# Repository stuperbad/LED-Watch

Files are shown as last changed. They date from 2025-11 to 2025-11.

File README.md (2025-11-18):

# LED-Watch
first schematic progress commit. adding RGB sketch schematic as well as
completed single LED ring sketch. need to add buttons and sort out AND
gates in the RGB sketch.
Product Ideas.. data sheets and store locations:

Boards options 

27 i/o pins and in the current sketch: https://www.digikey.com/en/products/detail/microchip-technology/ATMEGA4808-MUR/10444956

32 i/o pins: https://www.digikey.com/en/products/detail/microchip-technology/ATMEGA1284P-MU/1914520

LEDs options

addressable 1mm RGB: 
https://www.sparkfun.com/smd-led-addressable-rgb-apa-104-1010-pack-of-20.html
datasheet: https://cdn.sparkfun.com/assets/3/c/c/0/9/SparkFun_APA-104-1010__5mA__LED_Datasheet.pdf

nonaddressable 1mm RGB: 
https://www.digikey.com/en/products/detail/harvatek-corporation/B36J3RGB-F6C0001H4U1930/13588748

discrete white 0603:
https://www.digikey.com/en/products/detail/everlight-electronics-co-ltd/CSP0603AN101-WP30300563001-3T/15286660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

Button Options

19 cent 3.4mm square: https://www.digikey.com/en/products/detail/same-sky-formerly-cui-devices/TS21-34-035-BK-260-SMT-TR/21186457

8 cent 5.2mm square: https://www.digikey.com/en/products/detail/c-k/G01008829/16500348

Battery Parts:

Lipo Connector 
Thru-hole - 2mm.. they make 1mm mb? 
https://www.digikey.com/en/products/detail/jst-sales-america-inc/B2B-PH-K-S/926611

Coin Cell Harness
20mm dia. 3.
Do i need a negative connector? is SMD okay?
https://www.digikey.com/en/products/detail/keystone-electronics/3034TR/4499408

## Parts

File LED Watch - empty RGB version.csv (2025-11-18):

Reference | Qty | Value | DNP | Exclude from BOM | Exclude from Board | Footprint | Datasheet
RGB_LED1,RGB_LED2,RGB_LED3,RGB_LED4,RGB_LED5,RGB_LED6,RGB_LED7,RGB_LED8,RGB_LED9,RGB_LED10,RGB_LED11,RGB_LED12,RGB_LED13,RGB_LED14,RGB_LED15,RGB_LED16,RGB_LED17,RGB_LED18,RGB_LED19,RGB_LED20,RGB_LED21,RGB_LED22,RGB_LED23,RGB_LED24,RGB_LED25,RGB_LED26,RGB_LED27,RGB_LED28,RGB_LED29,RGB_LED30,RGB_LED31,RGB_LED32,RGB_LED33,RGB_LED34,RGB_LED35,RGB_LED36,RGB_LED37,RGB_LED38,RGB_LED39,RGB_LED40,RGB_LED41,RGB_LED42,RGB_LED43,RGB_LED44,RGB_LED45,RGB_LED46,RGB_LED47,RGB_LED48,RGB_LED49,RGB_LED50,RGB_LED51,RGB_LED52,RGB_LED53,RGB_LED54,RGB_LED55,RGB_LED56,RGB_LED57,RGB_LED58,RGB_LED59,RGB_LED60,RGB_LED61,RGB_LED62,RGB_LED63,RGB_LED64,RGB_LED65,RGB_LED66,RGB_LED67,RGB_LED68,RGB_LED69,RGB_LED70,RGB_LED71,RGB_LED72,RGB_LED73,RGB_LED74,RGB_LED75,RGB_LED76,RGB_LED77,RGB_LED78,RGB_LED79,RGB_LED80,RGB_LED81,RGB_LED82,RGB_LED83,RGB_LED84,RGB_LED85,RGB_LED86,RGB_LED87,RGB_LED88,RGB_LED89,RGB_LED90,RGB_LED91,RGB_LED92,RGB_LED93,RGB_LED94,RGB_LED95,RGB_LED96,RGB_LED97,RGB_LED98,RGB_LED99,RGB_LED100,RGB_LED101,RGB_LED102,RGB_LED103,RGB_LED104,RGB_LED105,RGB_LED106,RGB_LED107,RGB_LED108,RGB_LED109,RGB_LED110,RGB_LED111,RGB_LED112,RGB_LED113,RGB_LED114,RGB_LED115,RGB_LED116,RGB_LED117,RGB_LED118,RGB_LED119,RGB_LED120,RGB_LED121,RGB_LED122,RGB_LED123,RGB_LED124,RGB_LED125,RGB_LED126,RGB_LED132,RGB_LED133,RGB_LED134,RGB_LED135,RGB_LED136,RGB_LED137 | 132 | LTST-C19HE1WT |  |  |  | digikey-footprints:LED_Dual0603 | http://optoelectronics.liteon.com/upload/download/DS22-2008-0044/LTST-C19HE1WT.pdf
U1 | 1 | ATmega165PA-A |  |  |  | Package_QFP:TQFP-64_14x14mm_P0.8mm | http://ww1.microchip.com/downloads/en/DeviceDoc/atmel-8285-8-bit-avr-microcontroller-atmega165a_pa_325a_pa_3250a_pa_645a_p_6450a_p_datasheet.pdf

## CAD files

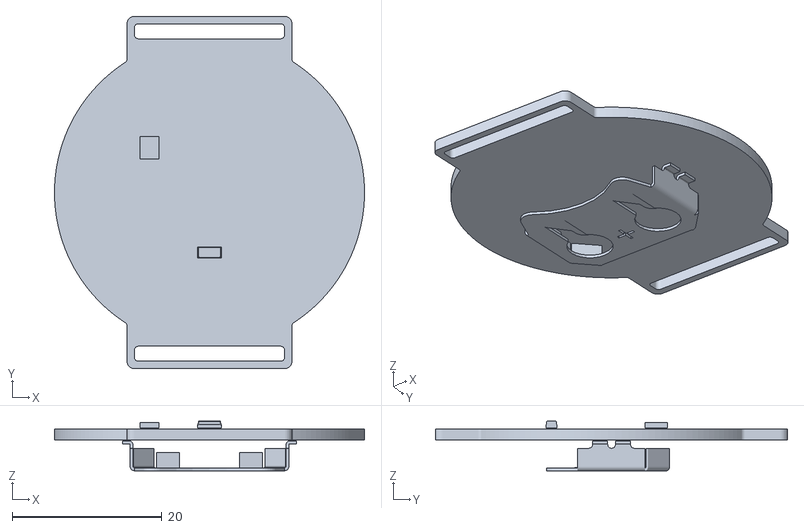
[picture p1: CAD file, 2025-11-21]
LED Watch.stl
41.3 x 47.0 x 6.61

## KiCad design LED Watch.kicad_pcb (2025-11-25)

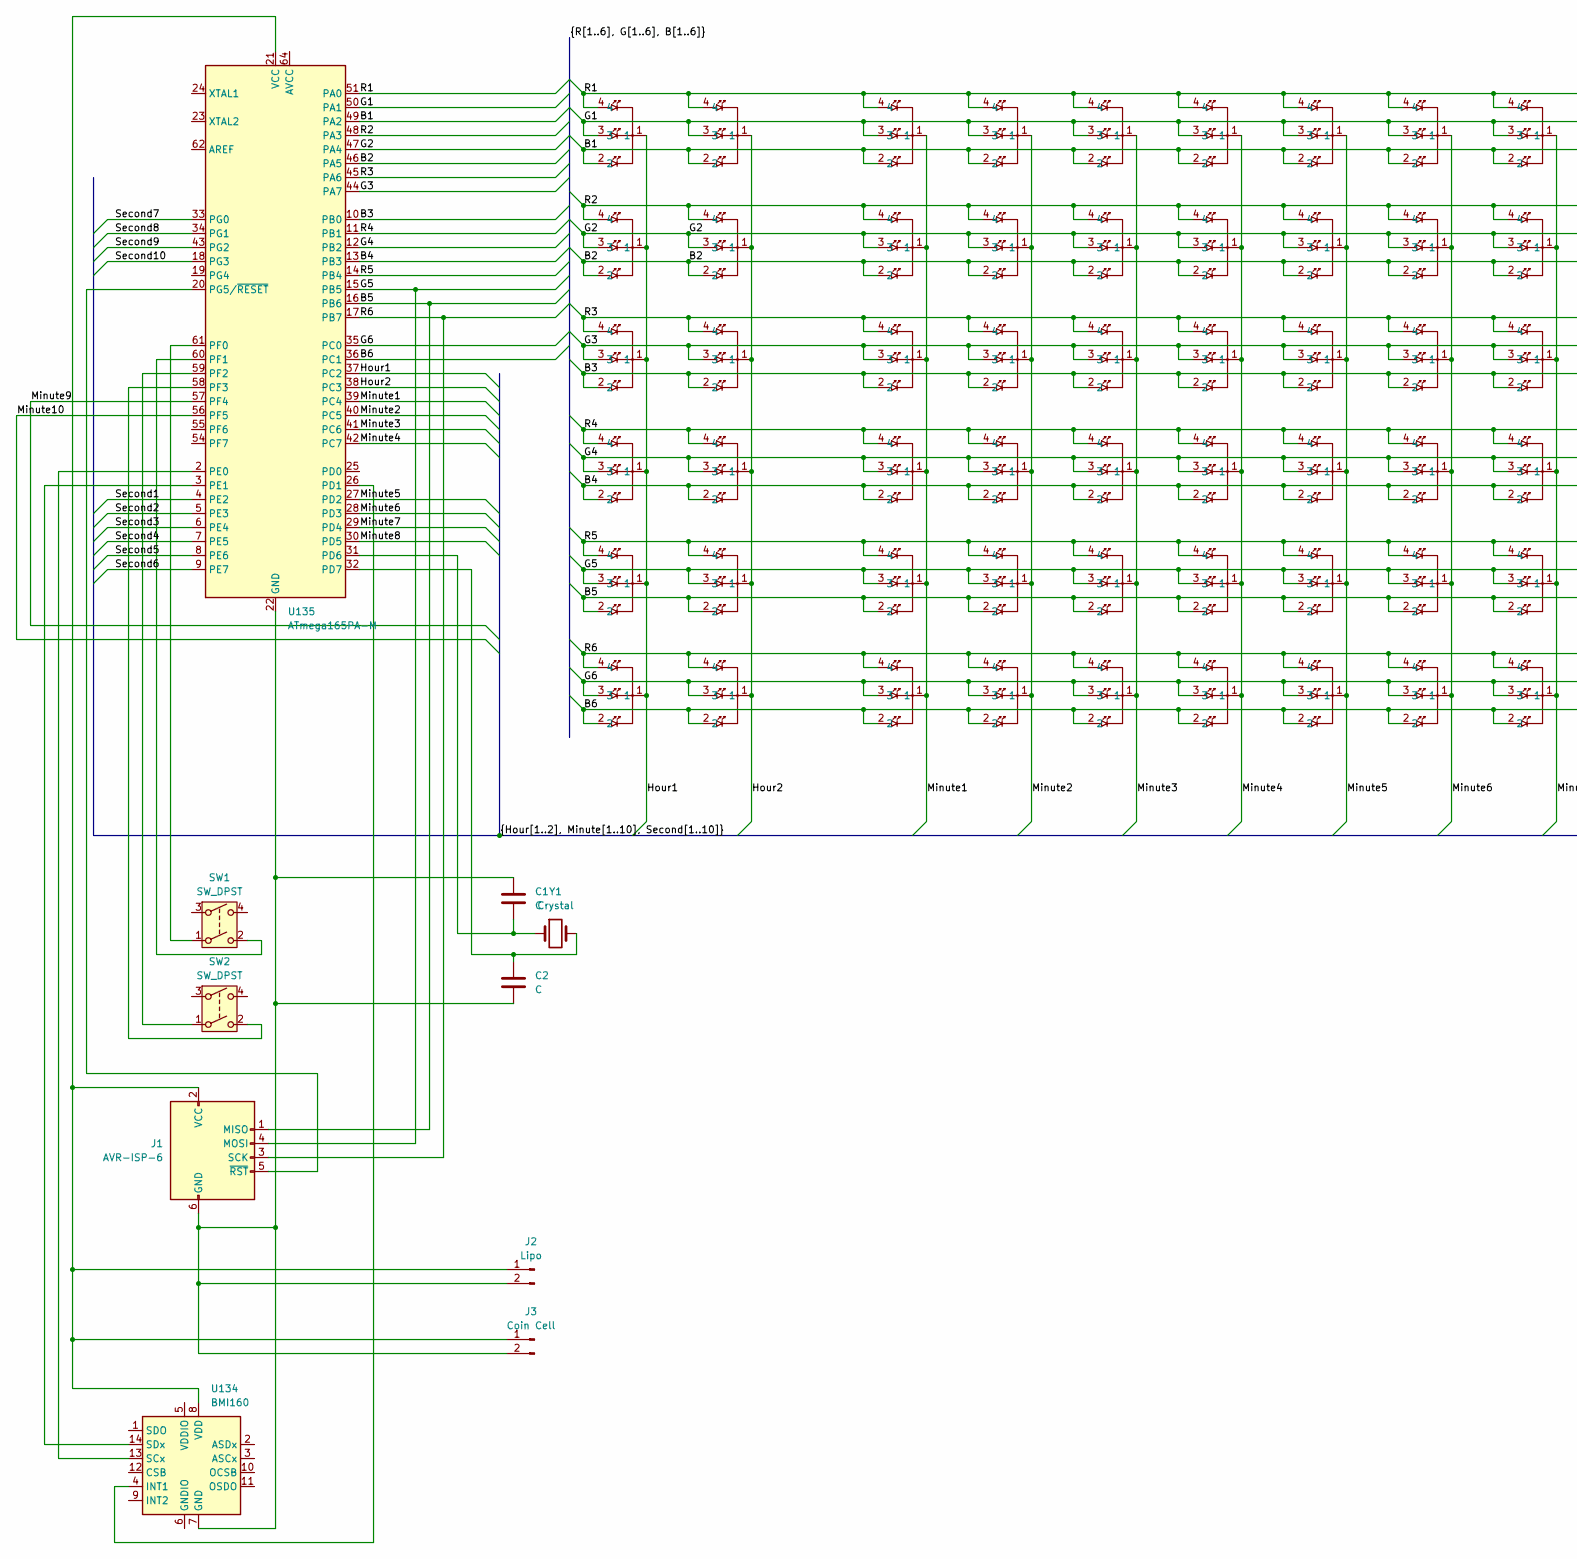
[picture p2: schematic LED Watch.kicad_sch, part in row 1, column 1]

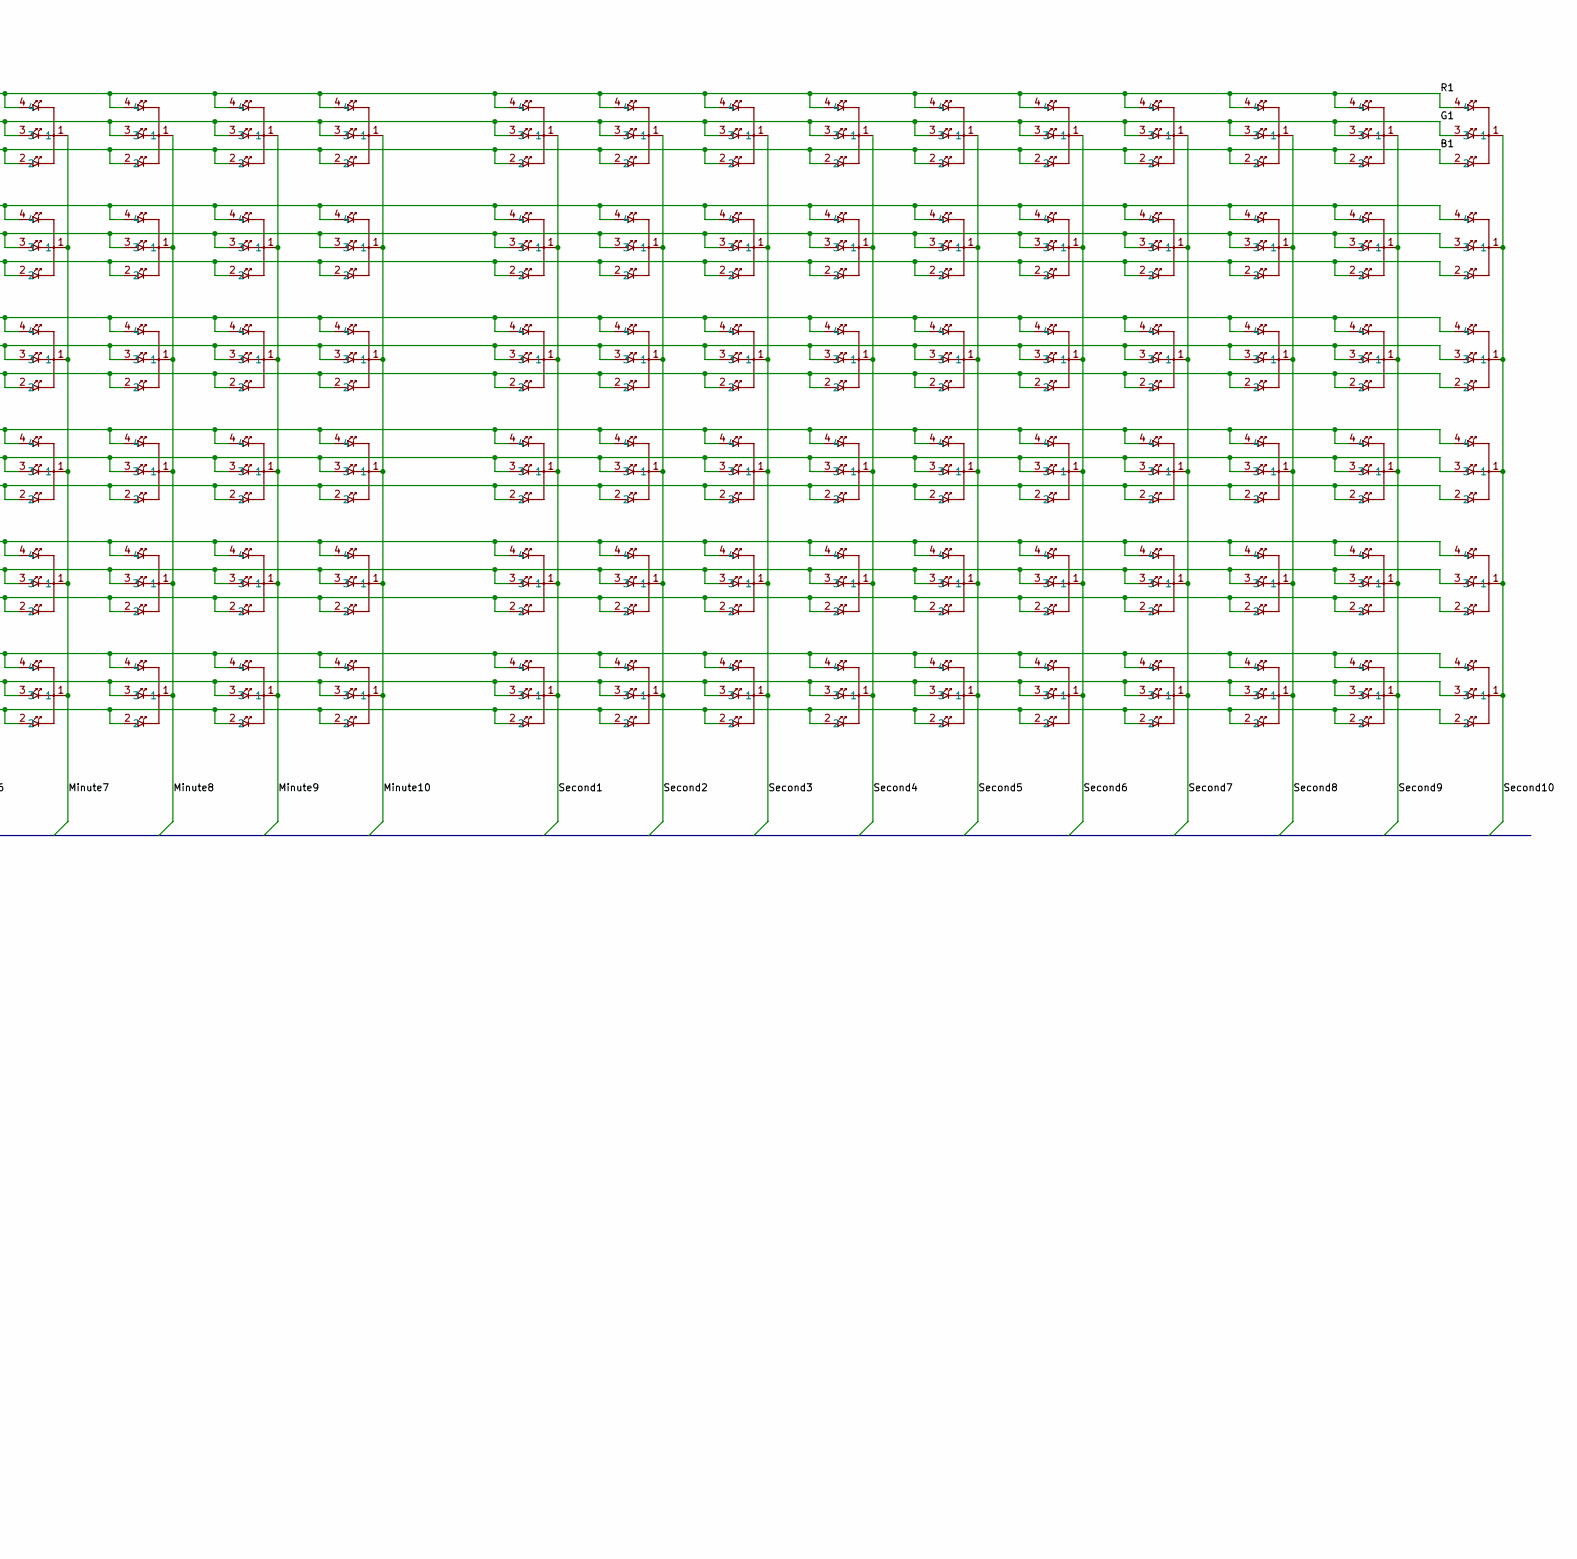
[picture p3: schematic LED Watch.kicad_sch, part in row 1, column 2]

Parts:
C1, C2: C; C_0201_0603Metric
J1: AVR-ISP-6; Tag-Connect_TC2030-IDC-NL_2x03_P1.27mm_Vertical
J2: Lipo; JST_SH_SM02B-SRSS-TB_1x02-1MP_P1.00mm_Horizontal
J3: Coin Cell; BatteryHolder_Keystone_3034_1x20mm
SW1, SW2: SW_DPST; SW_TS21-34-035-BK-260-SMT-TR
U2, U3, U4, U5, U6, U7, U8, U9, U10, U11, U12, U13, U14, U15, U16, U17, U18, U19, U20, U21, U22, U23, U24, U25, U26, U27, U28, U29, U30, U31, U32, U33, U34, U35, U36, U37, U38, U39, U40, U41, U42, U43, U44, U45, U46, U47, U48, U49, U50, U51, U52, U53, U54, U55, U56, U57, U58, U59, U60, U61, U62, U63, U64, U65, U66, U67, U68, U69, U70, U71, U72, U73, U74, U75, U76, U77, U78, U79, U80, U81, U82, U83, U84, U85, U86, U87, U88, U89, U90, U91, U92, U93, U94, U95, U96, U97, U98, U99, U100, U101, U102, U103, U104, U105, U106, U107, U108, U109, U110, U111, U112, U113, U114, U115, U116, U117, U118, U119, U120, U121, U122, U123, U124, U125, U126, U127, U128, U129, U130, U131, U132, U133: B39D3RGB-F6C0001HOU1930; B39D3RGB-F6C0001HOU1930_HVK; MPN LTST-C19HE1WT; Digi-Key_PN 160-2162-1-ND
U134: BMI160; Bosch_LGA-14_3x2.5mm_P0.5mm
U135: ATmega165PA-M; QFN-64-1EP_9x9mm_P0.5mm_EP5.4x5.4mm
Y1: Crystal; Crystal_SMD_3215-2Pin_3.2x1.5mm

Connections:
/B1: U2.2, U8.2, U14.2, U20.2, U26.2, U32.2, U38.2, U44.2, U50.2, U56.2, U62.2, U68.2, U74.2, U80.2, U86.2, U92.2, U98.2, U104.2, U110.2, U116.2, U122.2, U128.2, U135.49 (PA2)
/B2: U3.2, U9.2, U15.2, U21.2, U27.2, U33.2, U39.2, U45.2, U51.2, U57.2, U63.2, U69.2, U75.2, U81.2, U87.2, U93.2, U99.2, U105.2, U111.2, U117.2, U123.2, U129.2, U135.46 (PA5)
/B3: U4.2, U10.2, U16.2, U22.2, U28.2, U34.2, U40.2, U46.2, U52.2, U58.2, U64.2, U70.2, U76.2, U82.2, U88.2, U94.2, U100.2, U106.2, U112.2, U118.2, U124.2, U130.2, U135.10 (PB0)
/B4: U5.2, U11.2, U17.2, U23.2, U29.2, U35.2, U41.2, U47.2, U53.2, U59.2, U65.2, U71.2, U77.2, U83.2, U89.2, U95.2, U101.2, U107.2, U113.2, U119.2, U125.2, U131.2, U135.13 (PB3)
/B5: J1.1 (MISO), U6.2, U12.2, U18.2, U24.2, U30.2, U36.2, U42.2, U48.2, U54.2, U60.2, U66.2, U72.2, U78.2, U84.2, U90.2, U96.2, U102.2, U108.2, U114.2, U120.2, U126.2, U132.2, U135.16 (PB6)
/B6: U7.2, U13.2, U19.2, U25.2, U31.2, U37.2, U43.2, U49.2, U55.2, U61.2, U67.2, U73.2, U79.2, U85.2, U91.2, U97.2, U103.2, U109.2, U115.2, U121.2, U127.2, U133.2, U135.36 (PC1)
/G1: U2.3, U8.3, U14.3, U20.3, U26.3, U32.3, U38.3, U44.3, U50.3, U56.3, U62.3, U68.3, U74.3, U80.3, U86.3, U92.3, U98.3, U104.3, U110.3, U116.3, U122.3, U128.3, U135.50 (PA1)
/G2: U3.3, U9.3, U15.3, U21.3, U27.3, U33.3, U39.3, U45.3, U51.3, U57.3, U63.3, U69.3, U75.3, U81.3, U87.3, U93.3, U99.3, U105.3, U111.3, U117.3, U123.3, U129.3, U135.47 (PA4)
/G3: U4.3, U10.3, U16.3, U22.3, U28.3, U34.3, U40.3, U46.3, U52.3, U58.3, U64.3, U70.3, U76.3, U82.3, U88.3, U94.3, U100.3, U106.3, U112.3, U118.3, U124.3, U130.3, U135.44 (PA7)
/G4: U5.3, U11.3, U17.3, U23.3, U29.3, U35.3, U41.3, U47.3, U53.3, U59.3, U65.3, U71.3, U77.3, U83.3, U89.3, U95.3, U101.3, U107.3, U113.3, U119.3, U125.3, U131.3, U135.12 (PB2)
/G5: J1.4 (MOSI), U6.3, U12.3, U18.3, U24.3, U30.3, U36.3, U42.3, U48.3, U54.3, U60.3, U66.3, U72.3, U78.3, U84.3, U90.3, U96.3, U102.3, U108.3, U114.3, U120.3, U126.3, U132.3, U135.15 (PB5)
/G6: U7.3, U13.3, U19.3, U25.3, U31.3, U37.3, U43.3, U49.3, U55.3, U61.3, U67.3, U73.3, U79.3, U85.3, U91.3, U97.3, U103.3, U109.3, U115.3, U121.3, U127.3, U133.3, U135.35 (PC0)
/Hour1: U2.1, U3.1, U4.1, U5.1, U6.1, U7.1, U135.37 (PC2)
/Hour2: U8.1, U9.1, U10.1, U11.1, U12.1, U13.1, U135.38 (PC3)
/Minute1: U14.1, U15.1, U16.1, U17.1, U18.1, U19.1, U135.39 (PC4)
/Minute2: U20.1, U21.1, U22.1, U23.1, U24.1, U25.1, U135.40 (PC5)
/Minute3: U26.1, U27.1, U28.1, U29.1, U30.1, U31.1, U135.41 (PC6)
/Minute4: U32.1, U33.1, U34.1, U35.1, U36.1, U37.1, U135.42 (PC7)
/Minute5: U38.1, U39.1, U40.1, U41.1, U42.1, U43.1, U135.27 (PD2)
/Minute6: U44.1, U45.1, U46.1, U47.1, U48.1, U49.1, U135.28 (PD3)
/Minute7: U50.1, U51.1, U52.1, U53.1, U54.1, U55.1, U135.29 (PD4)
/Minute8: U56.1, U57.1, U58.1, U59.1, U60.1, U61.1, U135.30 (PD5)
/Minute9: U62.1, U63.1, U64.1, U65.1, U66.1, U67.1, U135.57 (PF4)
/Minute10: U68.1, U69.1, U70.1, U71.1, U72.1, U73.1, U135.56 (PF5)
/R1: U2.4, U8.4, U14.4, U20.4, U26.4, U32.4, U38.4, U44.4, U50.4, U56.4, U62.4, U68.4, U74.4, U80.4, U86.4, U92.4, U98.4, U104.4, U110.4, U116.4, U122.4, U128.4, U135.51 (PA0)
/R2: U3.4, U9.4, U15.4, U21.4, U27.4, U33.4, U39.4, U45.4, U51.4, U57.4, U63.4, U69.4, U75.4, U81.4, U87.4, U93.4, U99.4, U105.4, U111.4, U117.4, U123.4, U129.4, U135.48 (PA3)
/R3: U4.4, U10.4, U16.4, U22.4, U28.4, U34.4, U40.4, U46.4, U52.4, U58.4, U64.4, U70.4, U76.4, U82.4, U88.4, U94.4, U100.4, U106.4, U112.4, U118.4, U124.4, U130.4, U135.45 (PA6)
/R4: U5.4, U11.4, U17.4, U23.4, U29.4, U35.4, U41.4, U47.4, U53.4, U59.4, U65.4, U71.4, U77.4, U83.4, U89.4, U95.4, U101.4, U107.4, U113.4, U119.4, U125.4, U131.4, U135.11 (PB1)
/R5: U6.4, U12.4, U18.4, U24.4, U30.4, U36.4, U42.4, U48.4, U54.4, U60.4, U66.4, U72.4, U78.4, U84.4, U90.4, U96.4, U102.4, U108.4, U114.4, U120.4, U126.4, U132.4, U135.14 (PB4)
/R6: J1.3 (SCK), U7.4, U13.4, U19.4, U25.4, U31.4, U37.4, U43.4, U49.4, U55.4, U61.4, U67.4, U73.4, U79.4, U85.4, U91.4, U97.4, U103.4, U109.4, U115.4, U121.4, U127.4, U133.4, U135.17 (PB7)
/Second1: U74.1, U75.1, U76.1, U77.1, U78.1, U79.1, U135.4 (PE2)
/Second2: U80.1, U81.1, U82.1, U83.1, U84.1, U85.1, U135.5 (PE3)
/Second3: U86.1, U87.1, U88.1, U89.1, U90.1, U91.1, U135.6 (PE4)
/Second4: U92.1, U93.1, U94.1, U95.1, U96.1, U97.1, U135.7 (PE5)
/Second5: U98.1, U99.1, U100.1, U101.1, U102.1, U103.1, U135.8 (PE6)
/Second6: U104.1, U105.1, U106.1, U107.1, U108.1, U109.1, U135.9 (PE7)
/Second7: U110.1, U111.1, U112.1, U113.1, U114.1, U115.1, U135.33 (PG0)
/Second8: U116.1, U117.1, U118.1, U119.1, U120.1, U121.1, U135.34 (PG1)
/Second9: U122.1, U123.1, U124.1, U125.1, U126.1, U127.1, U135.43 (PG2)
/Second10: U128.1, U129.1, U130.1, U131.1, U132.1, U133.1, U135.18 (PG3)
unnamed: C1.1, C2.2, J1.6 (GND), J2.2, J3.2, U134.7 (GND), U135.22 (GND), U135.53 (GND), U135.63 (GND), U135.65 (GND)
unnamed: J1.2 (VCC), J2.1, J3.1, U134.8 (VDD), U135.21 (VCC), U135.52 (VCC)
unnamed: J1.5 (~RST), U135.20 (PG5/~RESET)
unnamed: U134.4 (INT1), U135.26 (PD1)
unnamed: U134.13 (SCx), U135.2 (PE0)
unnamed: U134.14 (SDx), U135.3 (PE1)
unnamed: C1.2, U135.31 (PD6), Y1.1
unnamed: C2.1, U135.32 (PD7), Y1.2
unnamed: SW1.1, U135.61 (PF0)
unnamed: SW1.2, U135.60 (PF1)
unnamed: SW2.1, U135.59 (PF2)
unnamed: SW2.2, U135.58 (PF3)

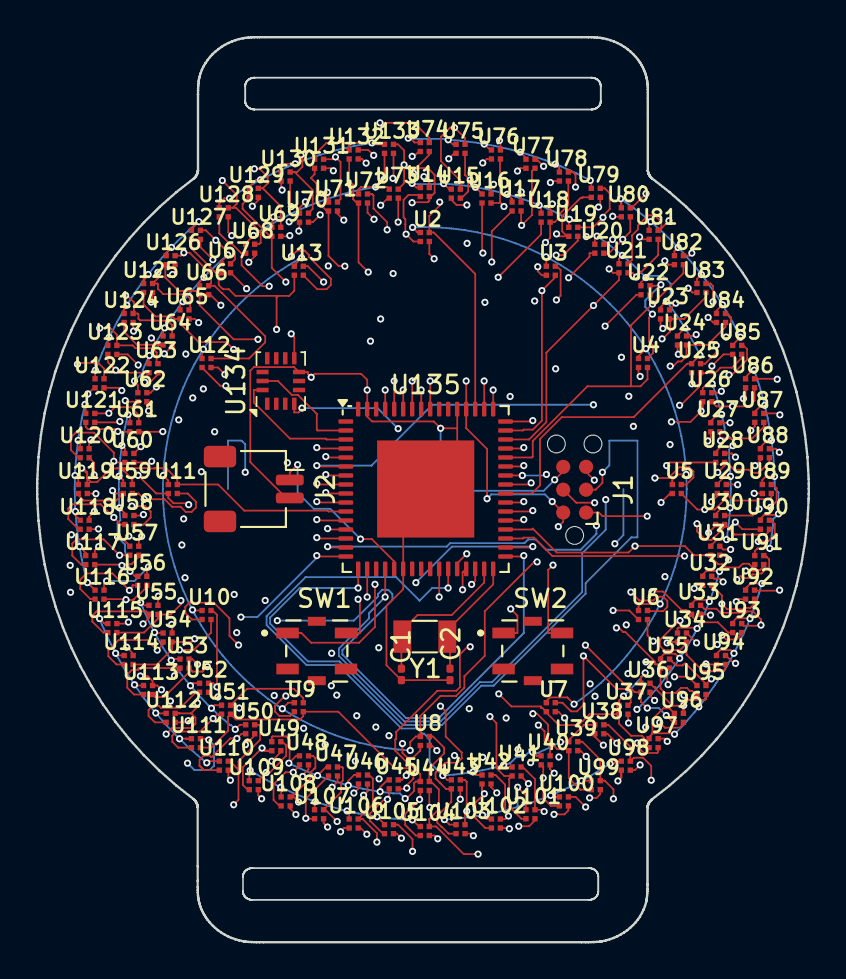
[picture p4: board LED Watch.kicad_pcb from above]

Board: 4 copper layers, 42.9 x 50.3 mm, 142 parts (1 on the bottom side), 52 nets.

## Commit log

2025-09-09 adding kicad files
    [LED Watch.kicad_pcb, LED Watch.kicad_sch]
2025-09-16 first schematic progress commit. adding RGB sketch schematic as well as completed single LED ring sketch. need to add buttons and sort out AND gates in the RGB sketch.
    [LED Watch - RGB version.kicad_sch, LED Watch.kicad_sch]
2025-09-16 chip swap to atmega4808
    [LED Watch - RGB version.kicad_sch, LED Watch.kicad_sch]
2025-10-13 added bus bars. things are where i think they should be but i need to double check transistors and do a lot more
    [LED Watch - RGB version.kicad_sch]
2025-11-18 added AVR 6 pin header, 2 buttons, lipo and coincell connectors, and idk.. stuff.. ready for pathing soon hopefully.
    [LED Watch - empty RGB version.csv, LED Watch - empty RGB version.dsn, LED Watch - empty RGB version.kicad_pcb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]
2025-11-18 adjusted clocking and spacings.. ready for routing
    [LED Watch - empty RGB version.kicad_pcb, LED Watch - empty RGB version.kicad_sch]
2025-11-21 adjusted clocking and spacings.. ready for routing again
    [LED Watch - RGB version - autopathing.kicad_pcb, LED Watch - empty RGB version v2.dsn, LED Watch - empty RGB version.kicad_pcb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]
2025-11-22 added caps.. still unsuccessful routing
    [LED Watch - RGB version - 4 layer.kicad_pcb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]
2025-11-25 traced out? iteration 1 at least.. passes an initial drc run.. I want to add a couple test regular white leds.. i should source and add for testing of potential single color board
    [LED Watch - RGB version - 4 layer WIP 11-23 .1mm traces 50PERCENT.kicad_pcb, LED Watch - RGB version - 4 layer WIP 11-23 .1mm traces 95PERCENT.kicad_pcb, LED W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]
2025-11-25 traced out, just a few minor cleanups.
    [LED Watch.kicad_pcb]
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2026-10-13 Reorganise into two variants: rgb/ (existing work, moved with history) and single-color/ (solar white-LED watch, board Y43)
    - git mv of all existing RGB files into rgb/ (history preserved)
    - single-color/: routed board, Gerbers, JLCPCB BOM/CPL, schematic generator, tools, docs, datasheets, firmware pin map and simulator
    - new root README explaining the layout
2026-10-14 single-color: board Y42 (42.0 mm), layout D, routed, DRC clean
    Placement-only work (hand-placed in KiCad, Y43_mockD_pogo8) turned into a routed board:
    - 42.0 mm outline (ring moved 0.75 mm inward), 2.5 mm strap slots, silkscreen numerals + weekday letters on the mode labels
    - real Murata piezo footprint (BZ1) on PB4/PB5, pogo programming pads (J2), 7th mode LED (ALM)
    - left-side crystal hookup, polar ring copper regenerated, rip-up router with no via-in-pad, merge onto the arc board
    - fab files (Gerber/drill zip) and BOM/CPL in boards/Y43/fab42, asm42
    - tools for each step; decision log updated
    DRC (project rules): 0 errors, 0 unconnected. NOT yet synced: schematic, firmware pin map; LED/cr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
2026-10-14 single-color: add the Y42 board files (routed board, fab and assembly files, hand placement)
    Whitelist boards/Y43/Y42_routed_v2*, fab42/, asm42/, Y43_mockD_pogo8 (Evan's hand placement, the source of the layout) and boards/X42 (ring planner output at 42 mm, outline source).
2026-10-14 single-color: Y42 v4 (ground plane rebuilt for the 42 mm outline), part checks, buzzer pin map
    - In2 ground-plane outline rebuilt from the current board outline and slots; includes Evan's BTN1 edit
    - regenerated Gerber/drill, BOM and placement files
    - buzzer on PB4/PB5 = TCA1 split mode, recorded in mcu-pinmaps.md and firmware/HANDOFF.md
    - decision log: footprint checks against the real parts and what could not be verified
2026-10-15 single-color: schematic regenerated to match Y42 v4; re-apply lost pad-landing and silk fixes; fab files re-exported
    - gen_schematic.py: 7 mode LEDs (IND7 = ALM), BZ1 piezo on BUZ_A/BUZ_B (PB4/PB5), RESET (PF6) to pogo pad 1, 4-pad pogo J2, dummy resistors R61-R67, SC1+/SC1- cell pads; watch_solar.kicad_sch regenerated. Netlist == board (197 parts, 0 differences apart from the far KMR2 switch pads).
    - Y42_routed_v4: IND7 value ALM; pad/via landing stubs, silk dashes removed, silk 0.15 mm, two-line mode labels re-applied (v4 had lost them), ground zone refilled. DRC 0 errors / 0 unconnected.
    - fab42/ and Y42_routed_v4_gerbers.zip re-exported, BOM/CPL regenerated, renders, DECISION-LOG and PRE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
2026-10-15 single-color firmware: ALM alarm mode, weekday on the indicator LEDs, buzzer (TCA1 split mode) with key/game sound settings; simulator sound; decision log (requote, JLCDFM, datasheet checks)
    - watch.c / watch_core.js: mode order TIME SET TMR ALM BAT FUN CFG, 7 indicators in face order, alarm, sound engine (watch_tone_hz / out.tone), CFG 11 key beeps, CFG 12 game sounds; both cores match on 20 scenarios incl. the buzzer frequency
    - hw/buzzer.c + buzzer_plan (tested), main.c integration, boot beep, pins/ledmap regenerated from the schematic netlist and the Y42 board
    - sim: Sound panel (WebAudio), alarm test, face data from the real Y42 board (export_face_board.py)
    - docs: MANUAL, DESIGN-UX, HA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
2026-10-15 single-color: add the project footprint library table next to Y42_routed_v4 (LEDWatch library opens without warnings)
2026-10-15 single-color: clean structure (hardware / firmware / docs / tools / archive), one KiCad project, revision A
    - hardware/: led-watch.kicad_pro / .kicad_sch / .kicad_pcb + footprints + fp/sym-lib-table (Y42_routed_v4 is now led-watch rev A), production/ (gerbers + zip, BOM, CPL; geometry identical to the prev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
    - docs/: all design notes, decision log, checklists, datasheets, research
    - tools/: routing pipeline incl. polar_*.py; README
    - archive/: 43.5 mm board generation, early generators, old schematic variant, scratch; local-only intermediates stay on disk, ignored by git
    - schematic generator writes led-watch.kic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
2026-10-15 Clean names: "LED Watch - Single Color" and "LED Watch - RGB" projects, dated pre-Claude archive for the RGB iterations
    - single-color/hardware: led-watch.* -> "LED Watch - Single Color".* (board, schematic, project, Gerbers, zip); generator, firmware tools and docs follow; production files regenerated (same geometry,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
    - rgb/: the latest RGB work (was "LED Watch.*") is now "LED Watch - RGB.*" with mechanical/, production/gerbers 2025-12-08/, scripts/; every older iteration (4 layer, WIP, 50PERCENT, 95PERCENT, autop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
    - READMEs for the repository, rgb/ and rgb/archive;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
2026-10-15 rgb: the live RGB work (Oct 2026 edits) becomes the main "LED Watch - RGB" project; add fab-rfq 2026-10-05, snapshots, Rhino layout
    - rgb/LED Watch - RGB.* = the files from the working folder as of 2026-10-14 (board routes with 0 unconnected nets); the December 2025 version that the repository had is kept in rgb/archive/pre-claude/2025-12-08 ...
    - rgb/production/fab-rfq 2026-10-05/ (BOM, placement files, Gerbers, DRC, quote screenshots, notes), rgb/archive/pre-claude/2026-10-05 snapshots ..., rgb/mechanical/watch layout 1.3dm
    - updated KiCad project/layout state files of the archived variants from the working folder
    - .gitignore: _old-desktop-copies/ (the previous loose Desktop copies, kept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
2026-10-15 docs: bring-up sheet for the first power-up (power architecture, battery polarity, one or two cells, programming, measurements)
2026-10-15 single-color: re-route nets out from under the MCU (U1) and the harvester (U4); gerbers re-exported; tools for it; decision log
    - BUZ_B off the In2 ground-plane layer; COL1, COL8_MCU, COL9_MCU, COL1_MCU, BUZ_B out of the MCU's 5x5 mm core; COL0_MCU partly (outside the centre); BTN2 and SDA out from under the BQ25570
    - DRC 0 errors / 0 unconnected; BOM and placement files unchanged
    - tools: reroute_prep.py, arcs_to_segments.py, prune_dangling_loop.py, prune_stub_vias.py
2026-10-15 single-color: snap every track end to its via/pad centre (475 ends), zone refilled, gerbers re-exported; snap_centers.py; decision log
2026-10-15 single-color: reach of the centre snap fixed (via radius + half track width), grid wobble straightened (2091 -> 1468 pieces), gerbers re-exported
2026-10-15 tools: octo_opt.py / octo_loop.py - shortest 0/45/90 re-draw of routed chains, checked against real KiCad shapes and DRC
2026-10-15 single-color: octilinear re-draw (non-45 pieces 790 -> 53), loose track joints welded to shared points, gerbers re-exported
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2026-10-15 docs: TinyCircuits ASR00011 70 mAh battery datasheet and what it means for the power design
2026-10-15 rgb-v2: placement sketch for a JLCPCB-assemblable RGB watch (44 mm board, 139 common-anode RGB LEDs, AVR128DB64), design notes, pin plan, BOM candidates
2026-10-16 rgb: the new RGB design takes over 'LED Watch - RGB'; the old routed RGB board (Harvatek, ATmega165PA) moves to rgb/archive; no 'v2' naming
2026-10-16 rgb: LEDs turned radially like the single-colour ring; MCU-on-front study and two front-MCU variant boards (DB48 + shift registers, DB64 with the cell shifted); build_sketch --variant
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2026-10-16 rgb: fix a count in the test table, ignore KiCad view-settings files
2026-10-16 rgb: column resistors in the hour-ring gaps (default), option for the row switches too, exact courtyard check, variant board and pictures
2026-10-19 single-color: pre-order review; VOUT divider R55/R56 to 7.32M/4.22M (inside the datasheet's recommended range), BOM 26 lines; review and no-oscilloscope bring-up test documents
2026-10-19 single-color: battery plug polarity swapped to match TinyCircuits' wiring (pin 1 = GND, pin 2 = BATT), local back rework + silk marks, schematic/netlist/gerbers/docs updated; review section 7
2026-10-19 single-color: buzzer traces (BUZ_A, BUZ_B, COL1) moved out from under the battery plug by hand; gerbers re-exported
2026-10-19 single-color: JLCPCB quote and JLCDFM results for the polarity-fixed board
2026-10-19 single-color: widen the three 0.1 mm gaps between COL1 and the buzzer traces; gerbers re-exported, JLCDFM trace spacing 0 red
2026-10-25 single-color: 3D-printable test models (blank board, board with big-part stand-ins, snap-on strap bumper), generator script, previews and print notes
2026-11-02 single-color: revision C (USB-C charging and UPDI programming) is the main design; rev B archived; layout, silkscreen and DFM clean-up
    Revision C replaces the 4-pad pogo programming row with a USB-C receptacle (J2, GCT USB4110) on the back at the rim:
    - UPDI programming over the two SBU pins (tied), 1 k series resistor, BAT54WS clamp to +3V3 against VBUS next to SBU; ground from the cable.
    - Charging over the same connector: BQ21040 (VBUS -> BATT, 54 mA, no thermistor), CC1 / CC2 5.1 k pull-downs, 1 uF in and out; in addition to the solar harvester.
    - RESET no longer wired out (no-connect in the schematic, internal pull-up in the firmware).
    - Fixed the solar cell pad net (SC1+ is /SOLAR_IN;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
2026-11-03 single-color firmware: optional activity meter (CFG page 3, Time progress on the minute ring, BAT view 4)
    Wrist motion beyond gravity is summed into points per day (1,000,000 mg.ms = 1 point, reset at midnight, clamped at 65,535). Off by default. CFG page 3 switches it on and sets the daily goal (250 to 4,000 points, default 1,000); holding Right in Time shows the day's progress as a bar on the minute ring next to the battery peek; BAT mode gets a fourth view while it is on.
    It counts only the IMU samples the firmware already reads (display on or the motion window after a wake-up), so it adds no sensor current but under-counts slow movement on a dark watch; an always-on FIFO sampler (about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
2026-11-03 single-color revision C: VBUS ESD clamp D51, USB-C corner re-arranged and hand-routed, C56 / U5 aligned, ERC clean-up, production files
    Schematic and library: ERC now 0 violations (a stray bracket in Local.kicad_sym, the IMU address pin typed as input, RESET as a no-connect); netlist.xml regenerated. New D51 (UMW UDD32C05L01, JLCPCB C19185929, 5 V bidirectional TVS, VBUS to GND) added next to C55 in the USB-C block; BOM 33 lines / 205 parts.
    Board (owner's layout, 2026-11-03): D51 next to D50, C50 and R68 in a row above them, C56 and U5 / C55 / R71 shifted 0.15-0.34 mm, the corner hand-routed; two cleanup passes (dangling via, pad exits along the part axis, ends on pad / via centres, micro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
2026-11-04 single-color docs: plain-language questions for the reviewer, D51 stock confirmed
    docs/QUESTIONS-FOR-JAMES.md: who-is-who table for the part labels and the four open questions (solar-charger part distances, MCU decoupling, inner-plane clearance, USB-C corner incl. SBU clamp to VBAT), the decided items, and the bench steps that are not questions. Review doc section 8 now points to it. JLCPCB parts page checked 2026-11-04: C19185929 (UMW UDD32C05L01) in stock, 5,109, $0.0322 at 1 piece; checklist H9 and review section 7 updated.
2026-11-04 single-color: In2 ground plane clearance 0.2 -> 0.1 mm, pictures of the review areas
    In2 GND zone clearance set to 0.1 mm (JLCPCB minimum 0.09 mm) and refilled; F.Cu crystal pour and the 0.2 mm hole-to-copper rule unchanged. DRC unchanged, 0 unconnected, keep-out 0, 65 of 65 nets one piece; only the In2 Gerber changed, zip regenerated. docs/review-areas-top-and-bottom.png and a back close-up colour the three areas the reviewer questions are about (solar charger parts, MCU power capacitors on the front, USB-C corner); QUESTIONS-FOR-JAMES.md is down to three questions.
2026-11-04 single-color: owner's ring / indicator clean-up (01:45 save), small errors fixed, via search
    Owner's hand pass over the LED rings, indicator row and crystal capacitors (vias 361 -> 345; C10 / R62 nudged 0.016 / 0.007 mm). Audit found and fixed: VBUS ends 2 micrometres apart, a 0.0001 mm sliver on COL4, a via on a straight BUZ_A line that connected nothing, ROW4 0.009 mm too close to C10 pad 2 (moved 0.02 mm), five collinear chops on ROW1. DRC back to the 12 known items, 0 unconnected, 65 of 65 nets one piece in the U-walk model.
    Via search over all non-GND, non-ring nets (121 vias): 23 hops + 17 bridges re-routed on a single layer with an A* (0.10 mm clearance, +0.6 mm detour); only VBUS ne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
2026-11-04 single-color: owner's 02:10 clean-up cycle, tick-off pass
    Owner's pass: pad exits off the part axis 20 -> 8 (Y1, L2, ring LEDs, resistors), vias 342. Audit fixes: four nested duplicate pieces, the COL3 T joint (0.0226 mm), a COL5 sliver and a zero-length VBAT piece, two collinear merges. DRC 12 known items, 0 unconnected, keep-out 0, 65 of 65 nets one piece. Remaining list in docs/DECISION-LOG.md (pad exits, two shallow pad landings, 45-degree forks, micro pieces). Production files regenerated.
2026-11-04 single-color: ring-LED pad exits along the part axis, R5.1 fork, overlaps (owner's 02:19 save)
    H11.1, H11.2, H5.2 and H7.2 now leave their pads along the part axis and meet the existing 45-degree line; R5.1's west COL4 line ends on the exit piece (the 15-degree V is gone); doubled +3V3 pieces at C30.1 and (102.9, 110.6) and a micro jog at (103.1, 98.75) cleaned up. Pad exits off the axis 4 -> 0, spots under 60 degrees 31 -> 23, DRC 12 known items, 0 unconnected, keep-out 0, 65 of 65 nets one piece. Micro pieces left alone on purpose. Pictures in docs/pad-exit-fixes.png and docs/overlap-fixes.png; production files regenerated.
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2026-11-09 single-color schematic: U1 datasheet link replaced (old Microchip address returned 403, new one checked)
2026-11-09 single-color: UPDI clamp D50 to BATT, inner layers swapped (ground plane on layer 2), crystal keep-out relaxed, 3D models for J2 / U1 / piezo / cell / batteries, pictures and docs
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
